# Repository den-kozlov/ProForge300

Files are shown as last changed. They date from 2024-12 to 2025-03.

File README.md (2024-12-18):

# ProForge 300 Tool Changer 3D Printer

P300 Render

Designed in the UK, the Proforge 300 Tool Changer is a state-of-the-art multi-tool 3D printer designed for precision, reliability, and modularity. With its advanced tool-changing mechanism, it enables seamless multi-material and multi-function printing for hobbyists, engineers, and makers.

Available to order [here.](https://www.makertech3d.com/pages/proforge-300)

# Features
	•	Tool-Changing Mechanism: Swap up to 3 tools in a single print.
	•	Large Build Volume: 300mm x 300mm x 300mm.
	•	Multi-Material Compatibility: Support for various filaments like PLA, ABS, PETG, and flexible materials.
	•	Advanced Calibration System: Automated nozzle alignment and offset calibration.
	•	Bed Scanning: A mesh of 2500 points is created in seconds for the perfect first layer.
	•	Klipper Firmware: High-speed and responsive motion control.

# ProForge 300 Klipper Firmware Image

The Klipper firmware image is available to download [here](https://mega.nz/file/s3c2yLpL#45p-zCgpL2xGsliyOl72hiXyFS9ZQuSpQ91LdNRgVnc).

# ProForge 300 Build Manual

The Official build guides for the ProForge 300 3D printer can be found [here](https://makertech-3d.dozuki.com/c/ProForge_300)

The BOM (Bill of Materials) can be found [here](https://docs.google.com/spreadsheets/d/11tMFYWeuSdlYLyPoK7uE3kZFWasaUpS3Rfe4Z1YwD74/edit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).

# Support and Community

If you run into any issues or need assistance with assembly or printing, feel free to ask for help in the official [Discord Server](https://discord.com/invite/FwgXFUw4R4)  or [Facebook Group](https://www.facebook.com/groups/proforge300).

If you’re missing a part or have received a faulty/broken one, please fill out [this form](https://www.makertech3d.com/missingpartform) for a replacement.

Want to get in touch? Drop us an email at info@makertech3d.com

# Safety Notice

Operate the ProForge 300 in a well ventilated, open and dry environment.

Be aware of the moving parts, there is a pinching hazard.

Be cautious of the Hotend, it can reach temperatures exceeding 300 degrees Celsius, this is hot enough to cause severe burns. Even after operation, the hotends can still be hot, allow time for them to cool before touching.

Keep children and pets away from the ProForge 300 whilst in operation.

Never disconnect any of the wiring whilst powered on.

Be careful of long hair and loose clothing when operating the ProForge 300.

Immediately shut down the ProForge 300 if an error occurs to prevent damage to the unit or its surroundings.

# Disclaimer

THIS PRODUCT IS A DO-IT-YOURSELF KIT TO BE ASSEMBLED BY THE USER AT THEIR OWN RISK. MAKERTECH 3D LTD DISCLAIMS ALL RESPONSIBILITY, RISK, OR LIABILITY OF ANY DAMAGE OR INJURY TO YOURSELF OR ANY PERSON OR PROPERTY FROM ITS USE.

NEITHER MAKERTECH 3D NOR ITS SUPPLIERS SHALL BE LIABLE TO YOU OR TO ANY THIRD PARTY FOR ANY INDIRECT, INCIDENTAL, CONSEQUENTIAL, SPECIAL, PUNITIVE, OR EXEMPLARY DAMAGES (INCLUDING IN EACH CASE, BUT NOT LIMITED TO, DAMAGES FOR THE INABILITY TO USE OR ACCESS THE PRODUCTS, LOSS OF DATA, LOSS OF BUSINESS, LOSS OF PROFITS, BUSINESS INTERRUPTION OR THE LIKE) ARISING OUT OF THE USE OF OR INABILITY TO USE THE PRODUCTS, EVEN IF MAKERTECH 3D HAS BEEN ADVISED OF THE POSSIBILITY OF SUCH DAMAGES.

MAKERTECH 3D IS NOT RESPONSIBLE FOR ANY PRODUCTS (3D PRINTED PARTS OR OTHER) PRODUCED WITH THE PROFORGE 3 OR ANY OF ITS OTHER PRODUCTS. IN NO EVENT SHALL MAKERTECH 3D BE LIABLE FOR ANY DAMAGE OR INJURY OCCURRED BY USING PRODUCTS PRODUCED BY THE PROFORGE 3 OR ANY OF ITS OTHER PRODUCTS.

NOTWITHSTANDING ANY DAMAGES THAT YOU MIGHT INCUR FOR ANY REASON WHATSOEVER (INCLUDING, WITHOUT LIMITATION, ALL DAMAGES REFERENCED HEREIN AND ALL DIRECT OR GENERAL DAMAGES IN CONTRACT OR ANYTHING ELSE), THE ENTIRE LIABILITY OF MAKERTECH 3D AND ANY OF ITS SUPPLIERS ARISING FROM OR RELATED TO THE USE OF THE PRODUCTS SHALL BE LIMITED TO THE AMOUNT ACTUALLY PAID BY YOU FOR THE PRODUCTS CONCERNED.

THE CUSTOMER IS FULLY AWARE OF THE TERMS OF USE MENTIONED IN THE ASSEMBLY MANUALS PROVIDED WITH THE PRODUCT AND AGREES WITH THESE TERMS OF USE WHEN ACCEPTING THE PRODUCT.

THE CUSTOMER HAS READ THE SAFETY INSTRUCTIONS PROVIDED IN THE MANUALS TO BUILD THE DIY-PRODUCTS OF MAKERTECH 3D. THE CUSTOMER ALSO AGREES IN FOLLOWING THESE SAFETY INSTRUCTIONS.

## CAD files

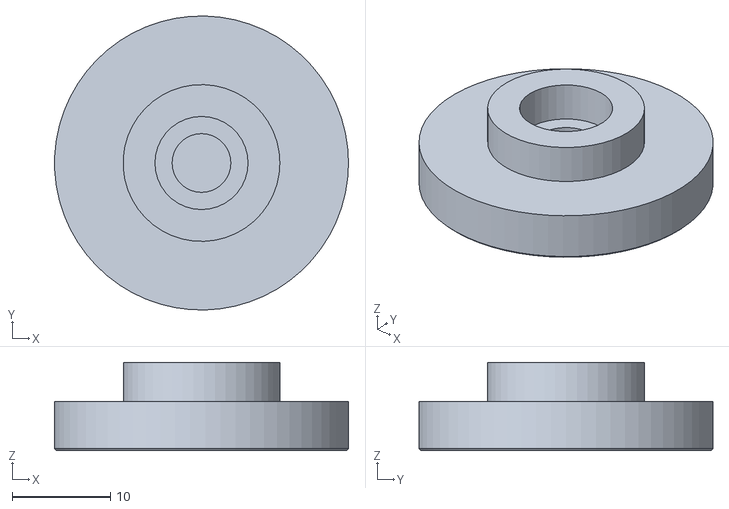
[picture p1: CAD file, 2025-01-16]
3D Printed Parts/Mods/Spool Holder Cover-2.STL
30.0 x 30.0 x 9.00

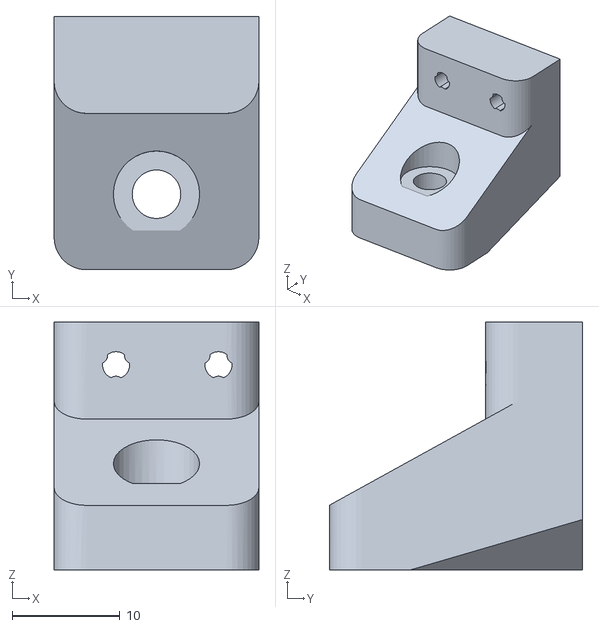
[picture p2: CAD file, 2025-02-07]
3D Printed Parts/P300_X-Endstop Mount.STL
19.0 x 23.5 x 23.0

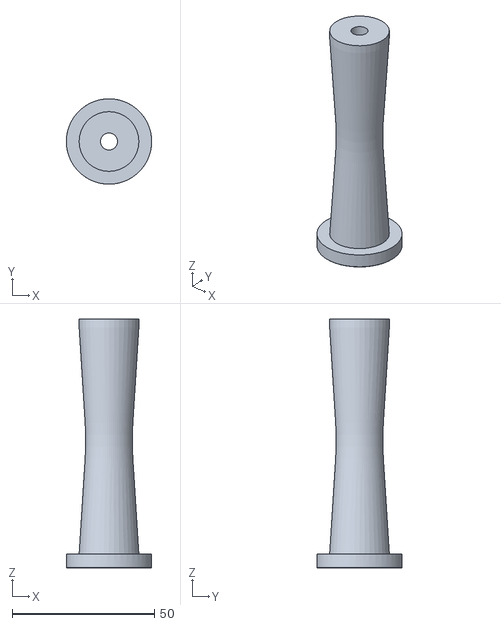
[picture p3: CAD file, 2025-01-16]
3D Printed Parts/Mods/Spool Holder Cover-1.STL
30.0 x 30.0 x 87.5

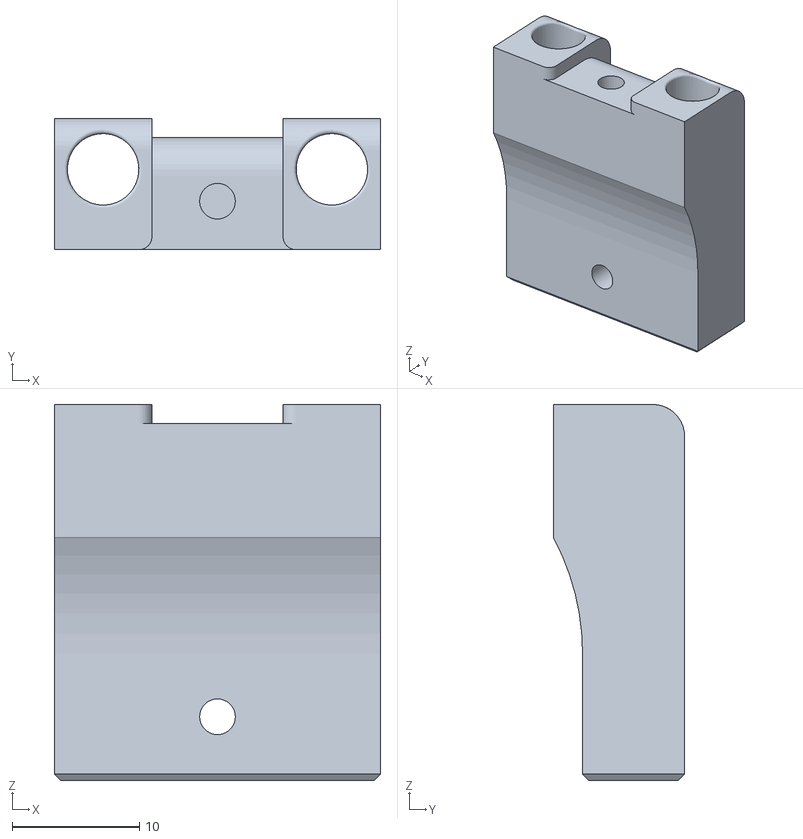
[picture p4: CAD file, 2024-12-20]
3D Printed Parts/P300_Docking Bracket.STL
25.6 x 10.3 x 29.5

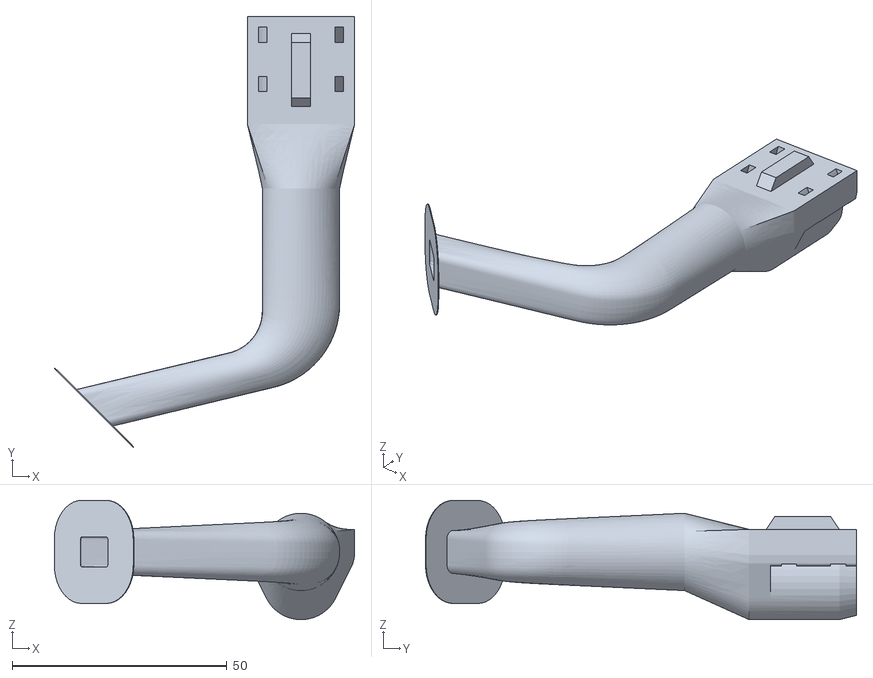
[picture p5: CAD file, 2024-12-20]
3D Printed Parts/P300_3D Printed Fan Shroud.STL
69.9 x 100.3 x 27.8

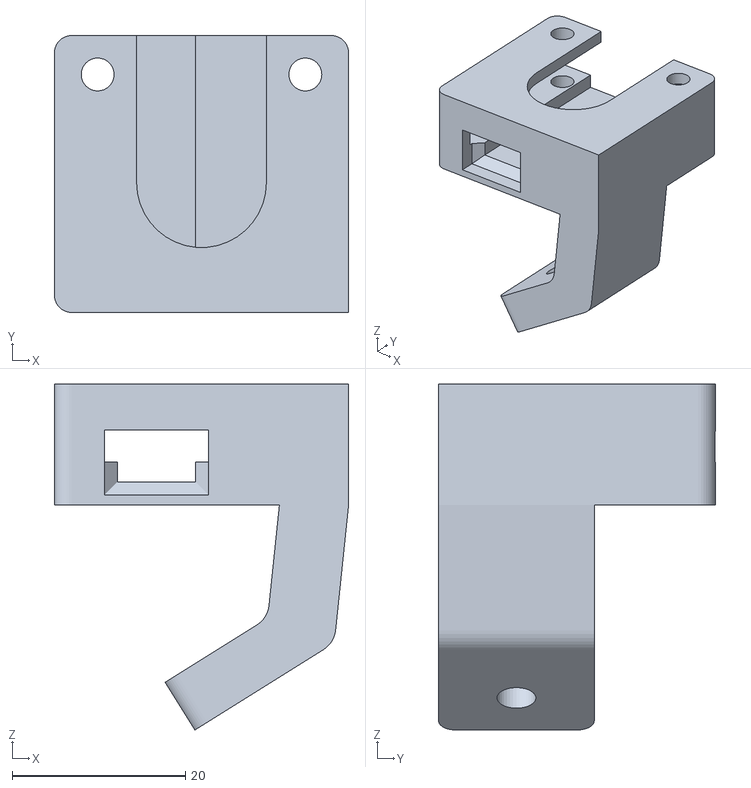
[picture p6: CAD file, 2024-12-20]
3D Printed Parts/P300_3D Printed Cam Case.STL
34.0 x 32.0 x 40.0

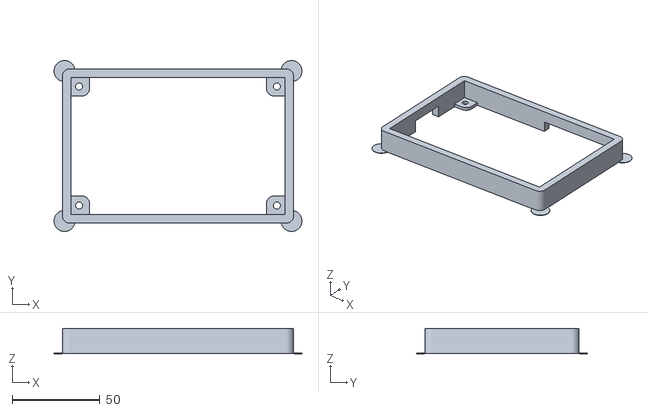
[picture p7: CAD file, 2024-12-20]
3D Printed Parts/P300_Screen Case.STL
141.7 x 97.7 x 14.5

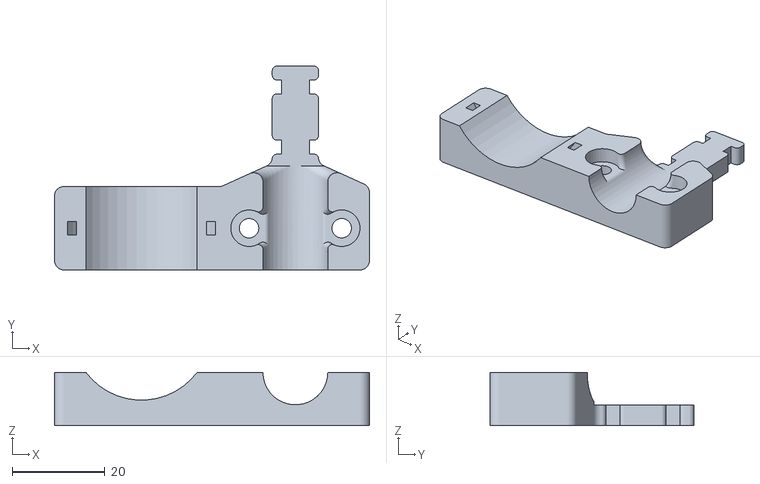
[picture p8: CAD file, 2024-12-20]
3D Printed Parts/P300_TC - Cable Relief.STL
68.0 x 44.0 x 11.5

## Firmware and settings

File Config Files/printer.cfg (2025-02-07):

############################################################################
####################### ProForge 300 Printer Config ########################
############################################################################

#config file version v1.1.0
#release date: 05.02.2025

# When updating this config file it is recommended to sun through
# the Eddy probe calibration and Input Shaping.

[include mainsail.cfg]
[include macros.cfg]
[include eddy.cfg]
[include calibrate-offsets.cfg]
#[include so3_0.cfg]
#[include so3_1.cfg]
#[include so3_2.cfg]


[save_variables]
filename: ~/printer_data/config/variables.cfg
#   Required - provide a filename that would be used to save the
#   variables to disk e.g. ~/variables.cfg
[virtual_sdcard]
path: ~/printer_data/gcodes

[force_move]
enable_force_move: True

[mcu]
serial: /dev/serial/by-id/

[exclude_object]

[printer]
kinematics: corexy
max_velocity: 800
max_accel: 60000
minimum_cruise_ratio: 0.65
square_corner_velocity: 10.0
max_z_velocity: 12
max_z_accel: 300

[gcode_arcs]
resolution: 0.2


# MOTOR-1
[stepper_x]
step_pin: PD4
dir_pin: !PD3
enable_pin: !PD6
rotation_distance: 40  # Adjust based on your lead screw or belt system
microsteps: 32
full_steps_per_rotation: 200  # Motor step angle: 1.8° = 200 steps per rotation
#gear_ratio: 1
#step_pulse_duration: 2  # Add if the driver requires a specific pulse width
endstop_pin: ^PC1
position_min: -100
position_endstop: 303
position_max: 303
homing_speed: 100  # mm/s; adjust for your mechanics
homing_retract_speed: 25  # mm/s
[tmc5160 stepper_x]
cs_pin: PD5
spi_speed: 2000000
spi_software_sclk_pin: PE14
spi_software_mosi_pin: PE13
spi_software_miso_pin: PE15
interpolate: True
run_current: 2.2  # Adjusted for 2.5A motor rating (approximately 85-90% for safety)
hold_current: 1.0  # Reduce for lower heat generation during idle
sense_resistor: 0.05
stealthchop_threshold: 0  # Disabled for better torque and stability on X-axis
# Driver Tuning
driver_TBL: 1
driver_TOFF: 3
driver_PWM_OFS: 30
driver_PWM_GRAD: 4
driver_HSTRT: 7
driver_HEND: 5


# MOTOR-2
[stepper_y]
step_pin: PA15
dir_pin: PA8
enable_pin: !PD1
rotation_distance: 40  # Adjust based on your belt/pulley system
microsteps: 32
full_steps_per_rotation: 200  # Motor step angle: 1.8° = 200 steps per rotation
#gear_ratio: 1
#step_pulse_duration: 2  # Add if the driver requires a specific pulse width
endstop_pin: ^PC3
position_min: 0
position_endstop: 300
position_max: 300
homing_speed: 100  # mm/s; adjust if necessary for your mechanics
homing_retract_speed: 25  # mm/s
[tmc5160 stepper_y]
cs_pin: PD0
spi_speed: 2000000
spi_software_sclk_pin: PE14
spi_software_mosi_pin: PE13
spi_software_miso_pin: PE15
interpolate: True
run_current: 2.2  # Adjusted to ~85-90% of the motor's rated 2.5A for safe operation
hold_current: 1.0  # Reduced for less heat generation during idle
sense_resistor: 0.05
stealthchop_threshold: 0  # Disabled to keep torque consistent for the Y-axis
# Driver Tuning
driver_TBL: 1
driver_TOFF: 3
driver_PWM_OFS: 30
driver_PWM_GRAD: 4
driver_HSTRT: 7
driver_HEND: 5


# MOTOR-3
[stepper_z]
step_pin: PE2
dir_pin: !PE3
enable_pin: !PE0
microsteps: 16
rotation_distance: 8
endstop_pin: probe:z_virtual_endstop
position_max: 300
position_min: -3.5
[tmc2209 stepper_z]
uart_pin: PE1
run_current: 0.6
sense_resistor: 0.11
stealthchop_threshold: 0
interpolate: True           # Enables interpolation for smoother movement
hold_current: 0.5           # Sets a lower current when idle to reduce heat

# MOTOR-4
[stepper_z1]
step_pin: PD15
dir_pin: !PD14
enable_pin: !PC7
microsteps: 16
rotation_distance: 8
[tmc2209 stepper_z1]
uart_pin: PC6
run_current: 0.6
sense_resistor: 0.11
stealthchop_threshold: 0
interpolate: True           # Enables interpolation for smoother movement
hold_current: 0.5           # Sets a lower current when idle to reduce heat

# MOTOR-5
[stepper_z2]
step_pin: PD11
dir_pin: !PD10
enable_pin: !PD13
microsteps: 16
rotation_distance: 8
[tmc2209 stepper_z2]
uart_pin: PD12
run_current: 0.6
sense_resistor: 0.11
stealthchop_threshold: 0
interpolate: True           # Enables interpolation for smoother movement
hold_current: 0.5           # Sets a lower current when idle to reduce heat


[heater_bed]
heater_pin: PB5
sensor_type: Generic 3950
sensor_pin: PA1
control: pid
pid_Kp: 64.083
pid_Ki: 3.338
pid_Kd: 307.600
min_temp: 0
max_temp: 115

[fan]
pin: PB7
max_power: 1.0
kick_start_time: 0.250

[fan_generic filter_fan]
pin: PB6
kick_start_time: 0.250


[z_tilt]
z_positions:
 -55, -16
 152.5, 356.54
 371, -16
points:
 1.2, 8.7
 121.2, 248.7
 241.2, 8.7
speed: 300
horizontal_move_z: 10
retries: 5
retry_tolerance: 0.2


[servo toolchanger]
pin: PC15
maximum_servo_angle: 180
minimum_pulse_width: 0.0005
maximum_pulse_width: 0.0025


[respond]
default_type: echo

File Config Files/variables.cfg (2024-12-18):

############################################################################
##################### ProForge 300 Variables Config ########################
############################################################################


#config file version v1.0.0
#release date: 18.12.2024


[Variables]

#Active Print Heads:
active_tools = 0			#Set to number of print heads installed.


# Tool Head SELECT Positions:

# Tool Head 0:
zero_select_x = 0
zero_select_y = 0

# Tool Head 1:
one_select_x = 0
one_select_y = 0

# Tool Head 2:
two_select_x = 0
two_select_y = 0


# Tool Head DOCKING Positions:

# Tool Head 0:
zero_dock_x = 0
zero_dock_y = 0

# Tool Head 1:
one_dock_x = 0
one_dock_y = 0

# Tool Head 2:
two_dock_x = 0
two_dock_y = 0




# Tool Head X/Y Offsets:

# Tool Head 0: 
# (0,0,0) - reference position


# Tool Head 1 Offset:
one_x_offset = 0
one_y_offset = 0
one_z_offset = 0

# Tool Head 2 Offset:
two_x_offset = 0
two_y_offset = 0
two_z_offset = 0

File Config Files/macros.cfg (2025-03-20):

############################################################################
########################## ProForge 300 Macros #############################
############################################################################

#config file version v1.1.0
#release date: 05.02.2025


[gcode_macro _END_PRINT]
gcode:
    # Dock active print head
    {% if printer.toolhead.extruder == "extruder" %}
        DOCK_T0
    {% elif printer.toolhead.extruder == "extruder1" %}
        DOCK_T1
    {% elif printer.toolhead.extruder == "extruder2" %}
        DOCK_T2
    {% endif %}
    # Turn off bed, extruder, and fan
    M140 S0
    M104 S0 T0
    M104 S0 T1
    M104 S0 T2
    M106 S0
    G1 X200 Y240 F16000
    # Disable steppers
    M84
    BED_MESH_CLEAR
    UPDATE_DELAYED_GCODE ID=FILTER_FAN_OFF DURATION=300


[gcode_macro CANCEL_PRINT]
description: Cancel the actual running print
rename_existing: CANCEL_PRINT_BASE
gcode:
  CLEAR_PAUSE
  _END_PRINT
  CANCEL_PRINT_BASE
  UPDATE_DELAYED_GCODE ID=FILTER_FAN_OFF DURATION=300

[gcode_macro PAUSE]
description: Pause the actual running print
rename_existing: PAUSE_BASE
gcode:
  PAUSE_BASE
  G91
  G1 Z20 F3000
  G90
  FRONT
  SET_IDLE_TIMEOUT TIMEOUT=86400 #one day in seconds


[gcode_macro RESUME]
description: Resume the actual running print
rename_existing: RESUME_BASE
gcode:
  RESUME_BASE
  SET_IDLE_TIMEOUT TIMEOUT=600

[gcode_macro _CHOME]
description: Homes XYZ axis only if printer is in a non-homed state
gcode:
  {% if "xyz" not in printer.toolhead.homed_axes %}
    G28
  {% endif %}

[gcode_macro _CHOME_TOOL]
description: Homes XY axis only if XY is in a non-homed state
gcode:
  {% if "xy" not in printer.toolhead.homed_axes %}
    G28 X Y
  {% endif %}

[gcode_macro CENTER]
description: Moves the toolhead to the center
gcode:
  _CHOME_TOOL
  {% set x_center = printer.toolhead.axis_maximum.x|float / 2.0 %}
  {% set y_center = printer.toolhead.axis_maximum.y|float / 2.0 %}
  G90
  G1 X{x_center} Y{x_center} F9000


[gcode_macro FRONT]
description: Moves the toolhead to the front
gcode:
  _CHOME_TOOL
  {% set x_center = printer.toolhead.axis_maximum.x|float / 2.0 %}
  {% set y_center = printer.toolhead.axis_maximum.y|float / 2.0 %}
  G90
  G1 X{x_center} Y10 F9000


[gcode_macro UNLOAD_FILAMENT]
description: Unload filament from the currently selected tool head
gcode:
  {% set extruder = printer.toolhead.extruder %}
  {% if extruder == "extruder" %}
      {% set tool_head = 0 %}
  {% elif extruder == "extruder1" %}
      {% set tool_head = 1 %}
  {% elif extruder == "extruder2" %}
      {% set tool_head = 2 %}
  {% else %}
      {% set tool_head = 0 %}
  {% endif %}

  M117 Unloading filament from Tool{tool_head}
  SET_LED LED=SO3RGB_{tool_head} RED=0.0 GREEN=0.5 BLUE=0.5
  _filament_unload_init_{tool_head}

[delayed_gcode FILTER_FAN_OFF]
gcode:
  SET_FAN_SPEED FAN=filter_fan SPEED=0

########################################
# Tool Changing Macros
########################################


[gcode_macro CAM_POSITION]
description: Set the servo cam angle
gcode:
  {% set serv_angle=params.A|default(0)|float %}
  SET_SERVO SERVO=toolchanger ANGLE={ serv_angle }   # Move servo arm
  G4 P1100                                           # Allow time to make move



[gcode_macro T0]
gcode:
  ACTIVATE_EXTRUDER EXTRUDER=extruder

[gcode_macro T1]
gcode:
  ACTIVATE_EXTRUDER EXTRUDER=extruder1

[gcode_macro T2]
gcode:
  ACTIVATE_EXTRUDER EXTRUDER=extruder2



[gcode_macro _OFFSET_RESET]
description: Reset any offsets.
gcode:
  SET_GCODE_OFFSET X=0
  SET_GCODE_OFFSET Y=0
  SET_GCODE_OFFSET Z=0

[gcode_macro _TOOL_CHECK]
description: Sanity check at beginning of print to ensure all print heads are docked.
gcode:
  PAUSE_BASE
  RESPOND MSG="Dock All Print Heads."


[gcode_macro _SERVO_DOCK]
gcode:
  SET_SERVO SERVO=toolchanger ANGLE=30               # Set cam release angle
  G4 P1100                                           # Allow time to make move

[gcode_macro _SERVO_SELECT]
gcode:
  SET_SERVO SERVO=toolchanger ANGLE=110              # Set cam locking angle
  G4 P1100                                           # Allow time to make move

[gcode_macro _PRIME]
gcode:
  {% if printer[printer.toolhead.extruder].temperature >= 165 %}
  G92 E0
  G0 E8 F3000
  G92 E0
  {% endif %}

[gcode_macro _WIPE]
gcode:
  {% if printer[printer.toolhead.extruder].temperature >= 165 %}
  G92 E0
  G0 E-0.5 F5000
  G92 E0
  {% endif %}
  G91
  G1 X+12 F3500
  G1 X-12 F3500
  G1 X+12 F3500
  G1 X-12 F3500
  G90

[gcode_macro _RETRACT]
gcode:
  {% if printer[printer.toolhead.extruder].temperature >= 170 %}
  G92 E0
  G0 E-10 F5000
  G92 E0
  {% endif %}

[gcode_macro _ZHOP]
gcode:
  {% if printer.virtual_sdcard.is_active %}
  G91
  G1 Z1 F2000
  G90
  {% endif %}






[gcode_macro SELECT_T0]
gcode:
  _CHOME_TOOL
  {% set svv = printer.save_variables.variables %}
  T0
  G90
  G0 Y{svv.zero_select_y} F30000
  G0 X{svv.zero_select_x + 7} F24000
  G0 X{svv.zero_select_x} F3000
  G0 Y{svv.zero_dock_y} F3000
  _SERVO_SELECT
  G0 X{svv.zero_select_x + 8} F12000
  _PRIME
  #_WIPE
  G0 X0 F12000
  {% if "xyz" in printer.toolhead.homed_axes %}
  SET_GCODE_OFFSET X=0
  SET_GCODE_OFFSET Y=0
  SET_GCODE_OFFSET Z=0
  {% endif %} 

[gcode_macro DOCK_T0]
gcode:
  _CHOME_TOOL
  {% set svv = printer.save_variables.variables %}
  _RETRACT
  _ZHOP
  _OFFSET_RESET
  G90
  G0 Y{svv.zero_dock_y} F30000
  G0 X{svv.zero_dock_x + 31}  F24000
  G0 X{svv.zero_dock_x} F12000
  _SERVO_DOCK
  G0 Y{svv.zero_select_y} F4000
  G0 X{svv.zero_dock_x + 10} F12000
  G0 X15 F24000
  





[gcode_macro SELECT_T1]
gcode:
  _CHOME_TOOL
  {% set svv = printer.save_variables.variables %}
  T1
  G90
  G0 Y{svv.one_select_y} F30000
  G0 X{svv.one_select_x + 10} F24000
  G0 X{svv.one_select_x} F3000
  G0 Y{svv.one_dock_y} F3000
  _SERVO_SELECT
  G0 X{svv.one_select_x + 8} F12000
  _PRIME
  #_WIPE
  G0 X0 F12000
  {% if "xyz" in printer.toolhead.homed_axes %}
  SET_GCODE_OFFSET X={svv.one_x_offset}
  SET_GCODE_OFFSET Y={svv.one_y_offset}
  SET_GCODE_OFFSET Z={svv.one_z_offset}
  {% endif %} 

[gcode_macro DOCK_T1]
gcode:
  _CHOME_TOOL
  {% set svv = printer.save_variables.variables %}
  _RETRACT
  _ZHOP
  _OFFSET_RESET
  G90
  G0 Y{svv.one_dock_y} F30000
  G0 X{svv.one_dock_x + 31}  F24000
  G0 X{svv.one_dock_x} F12000
  _SERVO_DOCK
  G0 Y{svv.one_select_y} F4000
  G0 X{svv.one_dock_x + 10} F12000
  G0 X15 F24000






[gcode_macro SELECT_T2]
gcode:
  _CHOME_TOOL
  {% set svv = printer.save_variables.variables %}
  T2
  G90
  G0 Y{svv.two_select_y} F30000
  G0 X{svv.two_select_x + 10} F24000
  G0 X{svv.two_select_x} F3000
  G0 Y{svv.two_dock_y} F3000
  _SERVO_SELECT
  G0 X{svv.two_select_x + 8} F12000
  _PRIME
  #_WIPE
  G0 X0 F12000
  {% if "xyz" in printer.toolhead.homed_axes %}
  SET_GCODE_OFFSET X={svv.two_x_offset}
  SET_GCODE_OFFSET Y={svv.two_y_offset}
  SET_GCODE_OFFSET Z={svv.two_z_offset}
  {% endif %} 

[gcode_macro DOCK_T2]
gcode:
  _CHOME_TOOL
  {% set svv = printer.save_variables.variables %}
  _RETRACT
  _ZHOP
  _OFFSET_RESET
  G90
  G0 Y{svv.two_dock_y} F30000
  G0 X{svv.two_dock_x + 31}  F24000
  G0 X{svv.two_dock_x} F12000
  _SERVO_DOCK
  G0 Y{svv.two_select_y} F4000
  G0 X{svv.two_dock_x + 15} F12000
  G0 X15 F24000
  

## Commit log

2024-12-20 3D Printed Files
    [P300_3D Printed Cam Case.STL, P300_3D Printed Fan Shroud.STL, P300_Docking Bracket.STL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]
2025-01-16 Spool Holder Cover
    [P300_Filament Guide.STL, P300_Spool Holder Cover.STL, Spool Holder Cover-1.STL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]
2025-01-20 Don't cancel every print
    [macros.cfg]
2025-01-29 Update P300_X-Endstop Mount.STL
    [P300_X-Endstop Mount.STL]
2025-02-05 Config Update v1.1
    [eddy.cfg, macros.cfg, printer.cfg]
2025-02-11 Config Update
    [eddy.cfg, macros.cfg]
